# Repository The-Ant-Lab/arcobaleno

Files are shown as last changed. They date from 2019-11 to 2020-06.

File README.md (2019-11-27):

# Arcobaleno<br/>A micropython development board made with The Ant.

This is our first complete project made with The Ant CNC machine.  
It is a development board designed by us and intended to be used with micropython.  

In this repository and in this video [The Ant + Micropython = ARCOBALENO](https://youtu.be/vV_R-Mp-2kI), you will find all the related information.  

If you want to realize the board with The Ant see the hardware folder.  
If you have already built the board and you want to use it see the firmware folder.  

If you liked this project and you want to help us develop new interesting projects, please consider donating using the paypal button here:

paypal (https://www.paypal.com/cgi-bin/webscr?cmd=_s-xclick&hosted_button_id=BTRCVPZUZYW2E)

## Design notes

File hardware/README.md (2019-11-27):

The hardware section is structured as follows:

- design, that contains the schematic and the board layout;
- cam, that contains the CAM outputs of the whole board, comprising gerbers and drill files.
- gcodes, that contains all the gcodes needed to execute the board machining with The Ant (see [here](https://www.youtube.com/channel/UCX44z-SSL7LzcB4xxgUdHHA)).

Before using the gcode files, read carefully the README in the gcodes folder.

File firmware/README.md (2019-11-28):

# Firmware folder structure

The firmware used on this project is based on [micropython](https://github.com/micropython/micropython).  

The firmware folder contains the following directories:  

- ARCOBALENO, that contains the configuration files needed to compile micropython for the Arcobaleno board  
- build-ARCOBALENO, that contains the micropython files already built for the Arcobaleno board  
- micropython, that is the submodule that will contain the micropython repository files.

If you want to use the already built micropython firmware on ARCOBALENO you may load the firmware.dfu or firmware.hex files, using respectively the DFU method with the USB connector or the SWD pins exposed on the ARCOBALENO board.

# Build micropython for ARCOBALENO

If you want to rebuild the micropython for the Arcobaleno board we suggest you to use a linux environment, clone this repository, initialize and update the micropython submodule, copy the whole ARCOBALENO folder in the micropython submodule in the "ports/stm32/boards" directory and then compile the micropython for the ARCOBALENO target board.  

Clone the repository:  
- git clone https://github.com/The-Ant-Lab/arcobaleno.git  

Enter in the firmware folder:  
- cd arcobaleno/firmware  

Initialize and update the micropython submodule:  
- git submodule init  
- git submodule update  

Copy the ARCOBALENO configuration folder in the proper path:
- cp -avr ARCOBALENO/ micropython/ports/stm32/boards/

Enter in the mpy-cross folder and compile it:
- cd micropython/mpy-cross
- make

Enter in the stm32 port folder (in this case from the mpy-cross folder):
- cd ../ports/stm32/

Compile micropython for the Arcobaleno board:
- make BOARD=ARCOBALENO

At the end of the compilation and linking in the "firmware/micropython/ports/stm32" folder there will be a new directory called "build-ARCOBALENO" containing all the built artifacts, and in particular the firmware images that can be uploaded to the Arcobaleno board.

If you want to clean this directory you may run the command:

- make clean BOARD=ARCOBALENO

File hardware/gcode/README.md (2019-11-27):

In this folder you can find the gcode files used to product Arcobaleno with The Ant.

You can see the results of milling operations in this video:

[The Ant + Micropython = ARCOBALENO](https://youtu.be/vV_R-Mp-2kI)

There are some key points to keep in mind before using these gcode files:

	1) The spindle motor used during the milling was a 1500Kv brushless motor
	2) Some grbl parameters were changed before the milling operation
	3) Higher feed rates have been used instead of the suggested ones

[1] The default spindle motor was a 1000Kv one, in theory using a faster motor should allow higher feed rates but with a loss in torque.
We wanted to test it so we changed the spindle motor. The results are pretty good.
   
[2] To allow a faster milling procedures we changed some grbl parameters:

- $110=2000.000 (x max rate, mm/min)
- $111=2000.000 (y max rate, mm/min)
- $112=200.000 (z max rate, mm/min)
- $120=200.000 (x accel, mm/sec^2)
- $121=200.000 (y accel, mm/sec^2)
- $122=10.000 (z accel, mm/sec^2)

Keep in mind that we don't use the max feedrate during milling but only for fast travel movements.

[3] With a faster spindle motor we have tested higher feed rates.
This change only impacts the top.gcode and bottom.gcode files.
If you want to change the feedrate in these files, you can open them in an text editor and change all the occurence of 'F200' with 'F90' (the default value with a spindle motor with 1000Kv).
In this way you can use the gcode files with a slower spindle motor.

Have fun!

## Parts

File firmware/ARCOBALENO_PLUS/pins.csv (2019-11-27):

X1 | PA2
X2 | PA3
X3 | PA0
X4 | PA1
X5 | PA4
X6 | PA5
X7 | PA6
X8 | PA7
X9 | PB6
X10 | PB7
X11 | PC4
X12 | PC5
X13 | Reset
X14 | GND
X15 | 3.3V
X16 | VIN
X17 | PB3
X18 | PC13
X19 | PC0
X20 | PC1
X21 | PC2
X22 | PC3
X23 | A3.3V
X24 | AGND
Y1 | PC6
Y2 | PC7
Y3 | PB10
Y4 | PB9
Y5 | PB12
Y6 | PB13
Y7 | PB14
Y8 | PB15
Y9 | PA8
Y10 | PB8
Y11 | PB0
Y12 | PB1
Y13 | Reset
Y14 | GND
Y15 | 3.3V
Y16 | VIN
SW | PB3
LED_BLUE | PB5
LED_RED | PB1
LED_GREEN | PB0
LED_YELLOW | PB4
SD_D0 | PC8
SD_D1 | PC9
SD_D2 | PC10
SD_D3 | PC11
SD_CMD | PD2
SD_CK | PC12
SD_SW | PA15
USB_VBUS | PA9
USB_DM | PA11
USB_DP | PA12
USB_ID | PA10
OSC32_IN | PC14
OSC32_OUT | PC15

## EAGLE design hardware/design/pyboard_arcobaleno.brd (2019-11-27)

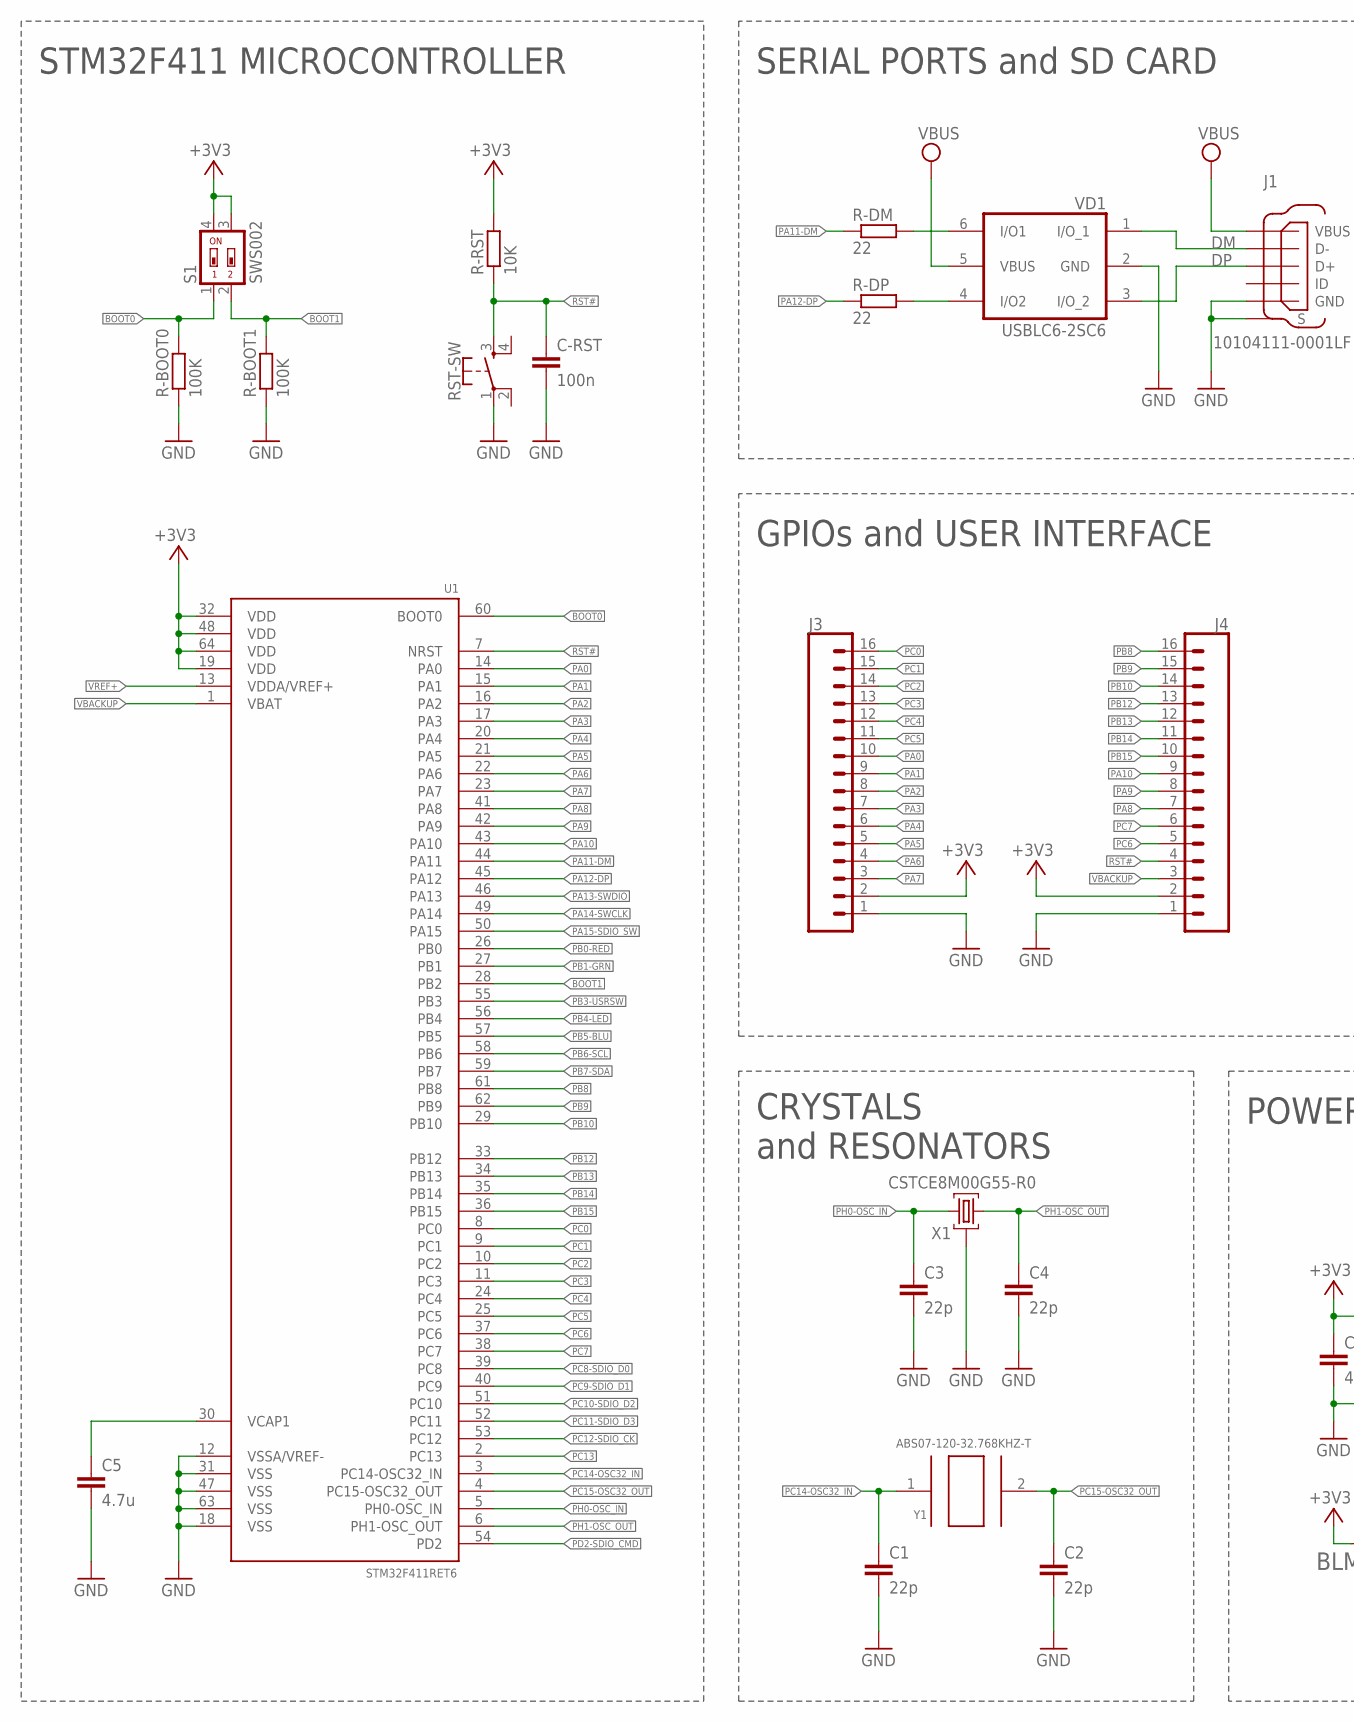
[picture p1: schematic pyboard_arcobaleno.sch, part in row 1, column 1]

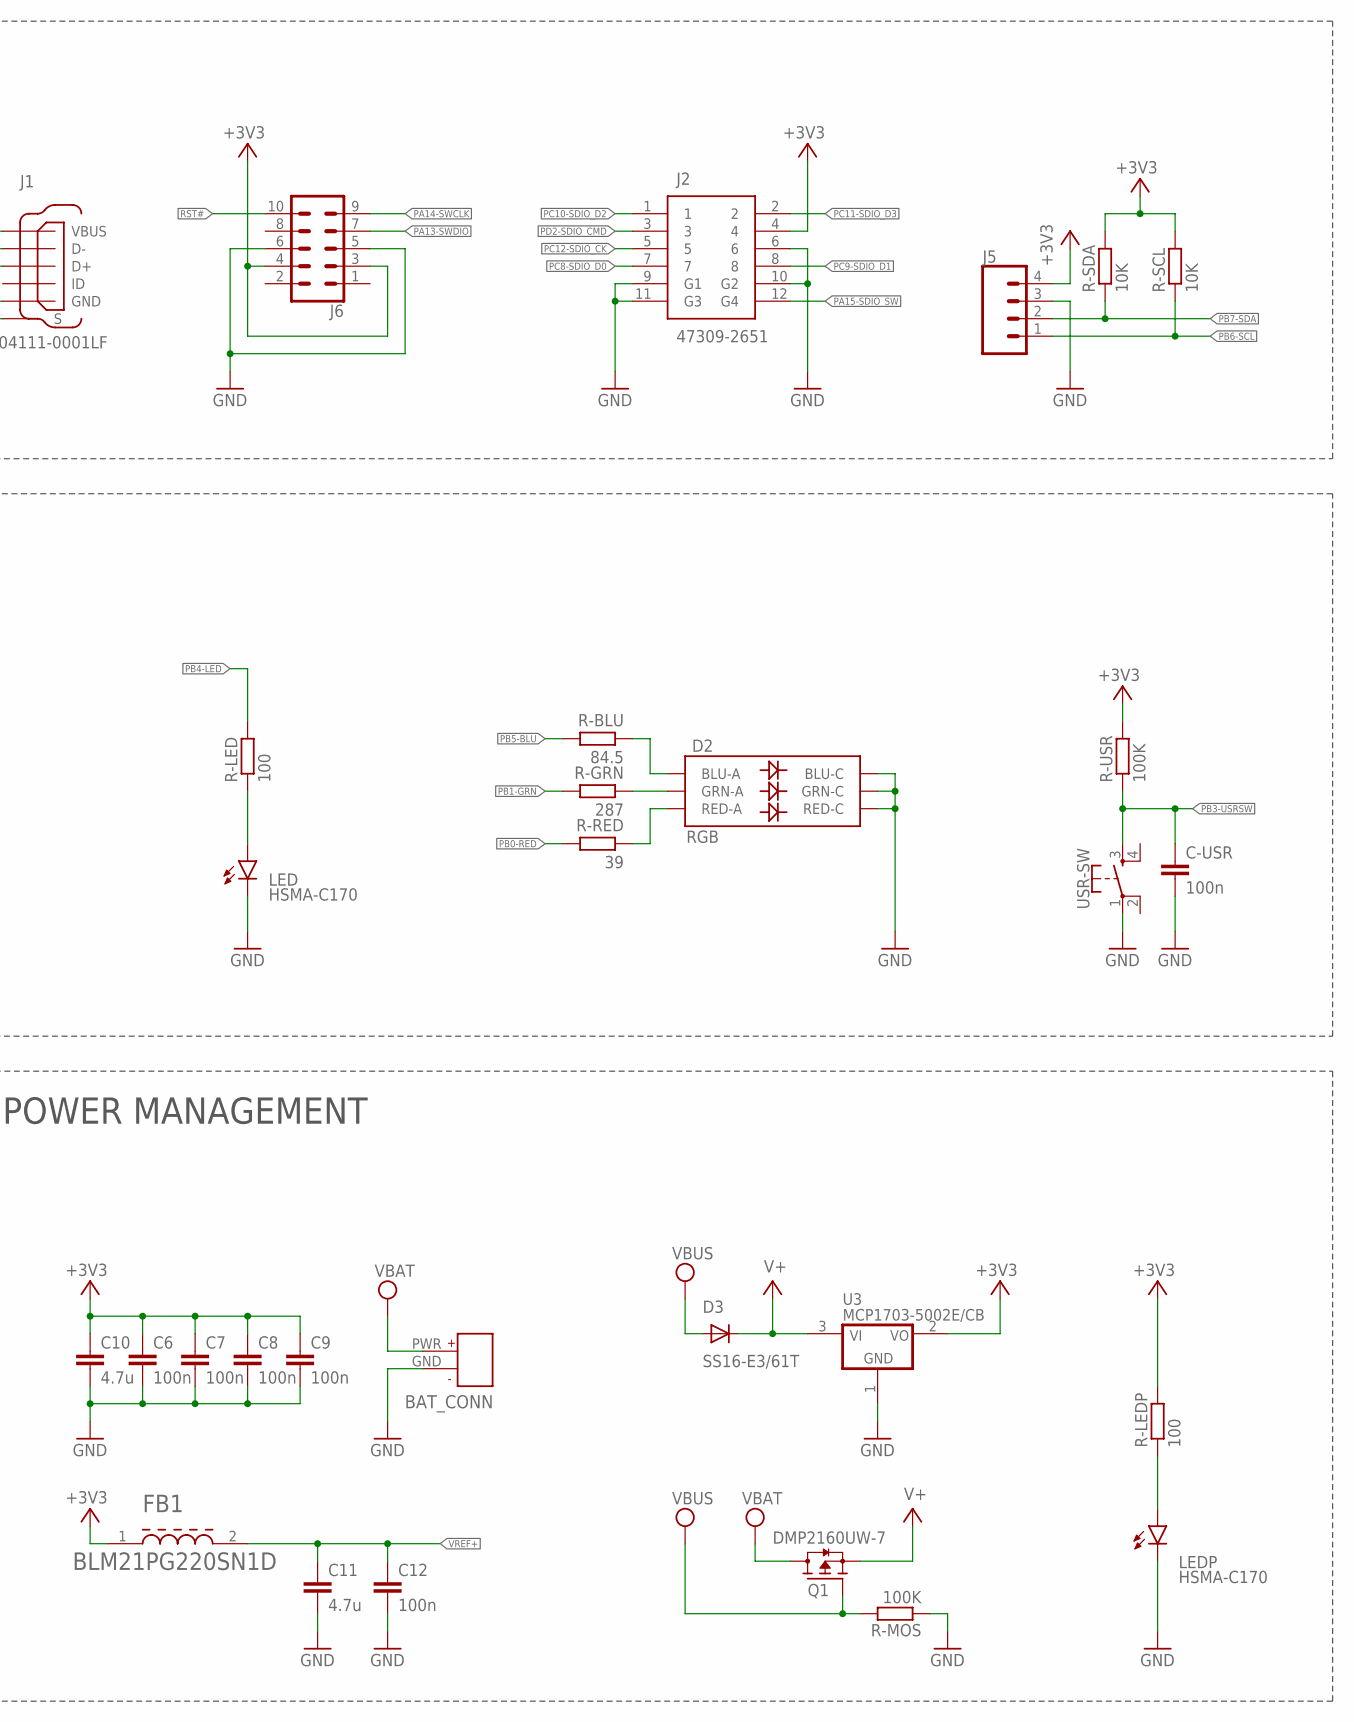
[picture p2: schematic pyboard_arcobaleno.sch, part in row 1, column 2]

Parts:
BAT_CONN: JST_PH_2PIN
C1, C2, C3, C4: 22p; C0603
C5, C10, C11: 4.7u; C1608
C6, C7, C8, C9, C12: 100n; C0603
C-RST: 100n; C0603
C-USR: 100n; C0603
D2: RGB; PLCC-6-LED
D3: SS16-E3/61T; DO214AA
FB1: MURATA_BLM21PG220SN1DMURATA_BLM21PG220SN1D_0_0; MURATA_BLM21PG220SN1D_0
J1: 10104111-0001LF; FRAMATOME_10104111-0001LF
J2: 47309-2651
J3, J4: CONN_16; 1X16
J5: CONN_04; 1X04
J6: CONN_05X2PTH; 2X5
LED: HSMA-C170; CHIPLED_0805
LEDP: HSMA-C170; CHIPLED_0805
Q1: DMP2160UW-7; SOT65P210X110-3N
R-BLU: 84.5; R0603
R-BOOT0, R-BOOT1: 100K; R0603
R-DM: 22; R0603
R-DP: 22; R0603
R-GRN: 287; R0603
R-LED: 100; R0603
R-LEDP: 100; R0603
R-MOS: 100K; R0603
R-RED: 39; R0603
R-RST: 10K; R0603
R-SCL: 10K; R0603
R-SDA: 10K; R0603
R-USR: 100K; R0603
RST-SW: MOMENTARY-SWITCH-SPST-2-SMD-5.2MM; TACTILE_SWITCH_SMD_5.2MM
S1: SWS002; SMS-002
U1: STM32F411RET6; QFP50P1200X1200X160-64N
U3: MCP1703-5002E/CB; SOT23A_MICROCHIP_CB
USR-SW: MOMENTARY-SWITCH-SPST-2-SMD-5.2MM; TACTILE_SWITCH_SMD_5.2MM
VD1: USBLC6-2SC6; SOT-23-6L
X1: CSTCE8M00G55-R0
Y1: ABS07-120-32.768KHZ-T; XTAL_ABS07-120-32.768KHZ-T

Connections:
+3V3: C6.1, C7.1, C8.1, C9.1, C10.1, FB1.1, J2.4, J3.2, J4.2, J5.4, J6.3, J6.4, R-LEDP.2, R-RST.2, R-SCL.2, R-SDA.2, R-USR.2, S1.3, S1.4, U1.19 (VDD), U1.32 (VDD), U1.48 (VDD), U1.64 (VDD), U3.2 (VO)
BOOT0: R-BOOT0.2, S1.1, U1.60 (BOOT0)
BOOT1: R-BOOT1.2, S1.2, U1.28 (PB2)
DM: J1.2 (D-), VD1.1 (I/O_1)
DP: J1.3 (D+), VD1.3 (I/O_2)
GND: BAT_CONN.GND, C1.2, C2.2, C3.2, C4.2, C5.2, C6.2, C7.2, C8.2, C9.2, C10.2, C11.2, C12.2, C-RST.2, C-USR.2, D2.CB (BLU-C), D2.CG (GRN-C), D2.CR (RED-C), J1.5 (GND), J1.6 (S), J1.7 (S), J1.8 (S), J1.9 (S), J2.6, J2.9 (G1), J2.10 (G2), J2.11 (G3), J3.1, J4.1, J5.3, J6.5, J6.6, LED.C, LEDP.C, R-BOOT0.1, R-BOOT1.1, R-MOS.1, RST-SW.1, U1.12 (VSSA/VREF-), U1.18 (VSS), U1.31 (VSS), U1.47 (VSS), U1.63 (VSS), U3.1 (GND), USR-SW.1, VD1.2 (GND), X1.2 (GND)
unnamed: C5.1, U1.30 (VCAP1)
unnamed: R-DM.2, VD1.6 (I/O1)
unnamed: R-DP.2, VD1.4 (I/O2)
unnamed: LED.A, R-LED.1
unnamed: LEDP.A, R-LEDP.1
unnamed: D2.AB (BLU-A), R-BLU.1
unnamed: D2.AG (GRN-A), R-GRN.1
unnamed: D2.AR (RED-A), R-RED.1
PA0: J3.10, U1.14 (PA0)
PA1: J3.9, U1.15 (PA1)
PA2: J3.8, U1.16 (PA2)
PA3: J3.7, U1.17 (PA3)
PA4: J3.6, U1.20 (PA4)
PA5: J3.5, U1.21 (PA5)
PA6: J3.4, U1.22 (PA6)
PA7: J3.3, U1.23 (PA7)
PA8: J4.7, U1.41 (PA8)
PA9: J4.8, U1.42 (PA9)
PA10: J4.9, U1.43 (PA10)
PA11-DM: R-DM.1, U1.44 (PA11)
PA12-DP: R-DP.1, U1.45 (PA12)
PA13-SWDIO: J6.7, U1.46 (PA13)
PA14-SWCLK: J6.9, U1.49 (PA14)
PA15-SDIO_SW: J2.12 (G4), U1.50 (PA15)
PB0-RED: R-RED.2, U1.26 (PB0)
PB1-GRN: R-GRN.2, U1.27 (PB1)
PB3-USRSW: C-USR.1, R-USR.1, U1.55 (PB3), USR-SW.3
PB4-LED: R-LED.2, U1.56 (PB4)
PB5-BLU: R-BLU.2, U1.57 (PB5)
PB6-SCL: J5.1, R-SCL.1, U1.58 (PB6)
PB7-SDA: J5.2, R-SDA.1, U1.59 (PB7)
PB8: J4.16, U1.61 (PB8)
PB9: J4.15, U1.62 (PB9)
PB10: J4.14, U1.29 (PB10)
PB12: J4.13, U1.33 (PB12)
PB13: J4.12, U1.34 (PB13)
PB14: J4.11, U1.35 (PB14)
PB15: J4.10, U1.36 (PB15)
PC0: J3.16, U1.8 (PC0)
PC1: J3.15, U1.9 (PC1)
PC2: J3.14, U1.10 (PC2)
PC3: J3.13, U1.11 (PC3)
PC4: J3.12, U1.24 (PC4)
PC5: J3.11, U1.25 (PC5)
PC6: J4.5, U1.37 (PC6)
PC7: J4.6, U1.38 (PC7)
PC8-SDIO_D0: J2.7, U1.39 (PC8)
PC9-SDIO_D1: J2.8, U1.40 (PC9)
PC10-SDIO_D2: J2.1, U1.51 (PC10)
PC11-SDIO_D3: J2.2, U1.52 (PC11)
PC12-SDIO_CK: J2.5, U1.53 (PC12)
PC13: U1.2 (PC13)
PC14-OSC32_IN: C1.1, U1.3 (PC14-OSC32_IN), Y1.1
PC15-OSC32_OUT: C2.1, U1.4 (PC15-OSC32_OUT), Y1.2
PD2-SDIO_CMD: J2.3, U1.54 (PD2)
PH0-OSC_IN: C3.1, U1.5 (PH0-OSC_IN), X1.1 (INPUT)
PH1-OSC_OUT: C4.1, U1.6 (PH1-OSC_OUT), X1.3 (OUTPUT)
RST#: C-RST.1, J4.4, J6.10, R-RST.1, RST-SW.3, U1.7 (NRST)
V+: D3.C, Q1.2 (S), U3.3 (VI)
VBACKUP: J4.3, U1.1 (VBAT)
VCC: D3.A, J1.1 (VBUS), Q1.1 (G), R-MOS.2, VD1.5 (VBUS)
VEE: BAT_CONN.PWR, Q1.3 (D)
VREF+: C11.1, C12.1, FB1.2, U1.13 (VDDA/VREF+)

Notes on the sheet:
STM32F411 MICROCONTROLLER
SERIAL PORTS and SD CARD
GPIOs and USER INTERFACE
CRYSTALS and RESONATORS
POWER MANAGEMENT

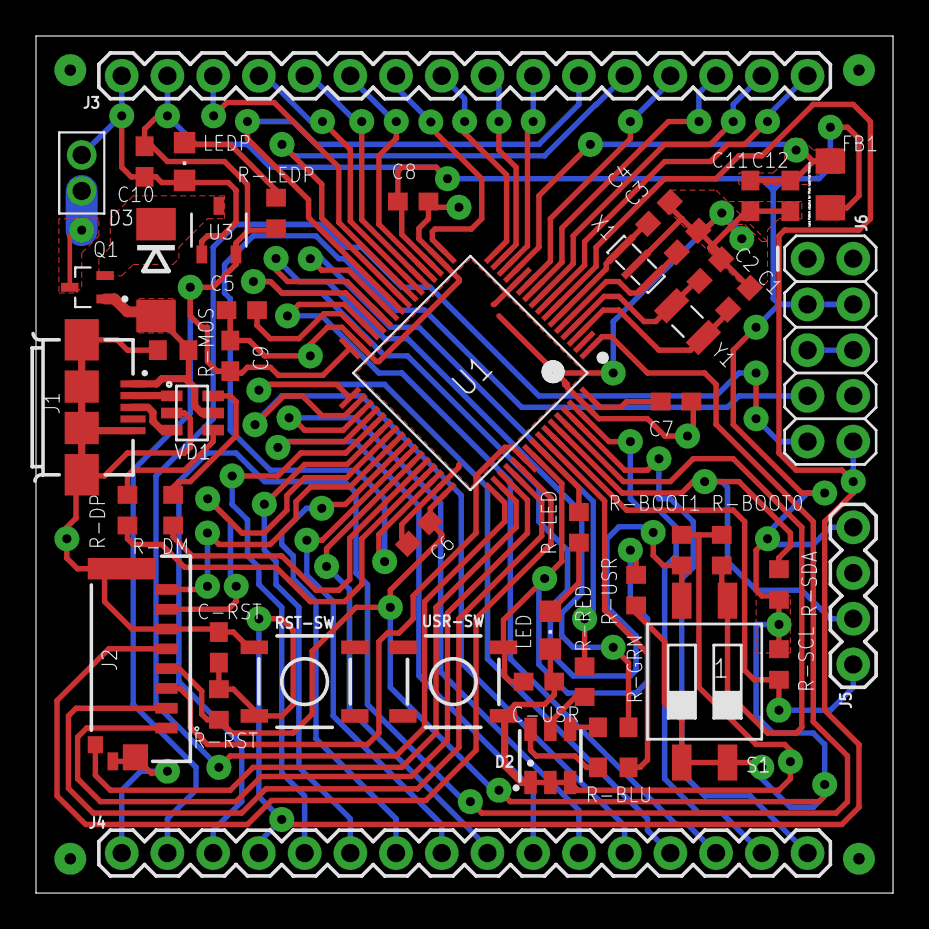
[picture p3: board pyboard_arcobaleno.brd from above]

Board: 2 copper layers, 47.6 x 47.6 mm, 49 parts (0 on the bottom side), 68 nets.

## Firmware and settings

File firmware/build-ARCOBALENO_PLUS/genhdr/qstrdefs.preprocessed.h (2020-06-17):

# 1 "<stdin>"
# 1 "<built-in>"
# 1 "<command-line>"
# 1 "<stdin>"
# 27 "<stdin>"
# 1 "../../py/mpconfig.h" 1
# 62 "../../py/mpconfig.h"
# 1 "./mpconfigport.h" 1
# 31 "./mpconfigport.h"
# 1 "boards/ARCOBALENO_PLUS/mpconfigboard.h" 1
# 32 "./mpconfigport.h" 2
# 1 "./mpconfigboard_common.h" 1
# 30 "./mpconfigboard_common.h"
# 1 "../../lib/stm32lib/STM32F4xx_HAL_Driver/Inc/stm32f4xx_hal.h" 1
# 48 "../../lib/stm32lib/STM32F4xx_HAL_Driver/Inc/stm32f4xx_hal.h"
# 1 "boards/ARCOBALENO_PLUS/stm32f4xx_hal_conf.h" 1







# 1 "./boards/stm32f4xx_hal_conf_base.h" 1
# 30 "./boards/stm32f4xx_hal_conf_base.h"
# 1 "../../lib/stm32lib/STM32F4xx_HAL_Driver/Inc/stm32f4xx_hal_dma.h" 1
# 47 "../../lib/stm32lib/STM32F4xx_HAL_Driver/Inc/stm32f4xx_hal_dma.h"
# 1 "../../lib/stm32lib/STM32F4xx_HAL_Driver/Inc/stm32f4xx_hal_def.h" 1
# 48 "../../lib/stm32lib/STM32F4xx_HAL_Driver/Inc/stm32f4xx_hal_def.h"
# 1 "../../lib/stm32lib/CMSIS/STM32F4xx/Include/stm32f4xx.h" 1
# 189 "../../lib/stm32lib/CMSIS/STM32F4xx/Include/stm32f4xx.h"
# 1 "../../lib/stm32lib/CMSIS/STM32F4xx/Include/stm32f413xx.h" 1
# 84 "../../lib/stm32lib/CMSIS/STM32F4xx/Include/stm32f413xx.h"
typedef enum
{

  NonMaskableInt_IRQn = -14,
  MemoryManagement_IRQn = -12,
  BusFault_IRQn = -11,
  UsageFault_IRQn = -10,
  SVCall_IRQn = -5,
  DebugMonitor_IRQn = -4,
  PendSV_IRQn = -2,
  SysTick_IRQn = -1,

  WWDG_IRQn = 0,
  PVD_IRQn = 1,
  TAMP_STAMP_IRQn = 2,
  RTC_WKUP_IRQn = 3,
  FLASH_IRQn = 4,
  RCC_IRQn = 5,
  EXTI0_IRQn = 6,
  EXTI1_IRQn = 7,
  EXTI2_IRQn = 8,
  EXTI3_IRQn = 9,
  EXTI4_IRQn = 10,
  DMA1_Stream0_IRQn = 11,
  DMA1_Stream1_IRQn = 12,
  DMA1_Stream2_IRQn = 13,
  DMA1_Stream3_IRQn = 14,
  DMA1_Stream4_IRQn = 15,
  DMA1_Stream5_IRQn = 16,
  DMA1_Stream6_IRQn = 17,
  ADC_IRQn = 18,
  CAN1_TX_IRQn = 19,
  CAN1_RX0_IRQn = 20,
  CAN1_RX1_IRQn = 21,
  CAN1_SCE_IRQn = 22,
  EXTI9_5_IRQn = 23,
  TIM1_BRK_TIM9_IRQn = 24,
  TIM1_UP_TIM10_IRQn = 25,
  TIM1_TRG_COM_TIM11_IRQn = 26,
  TIM1_CC_IRQn = 27,
  TIM2_IRQn = 28,
  TIM3_IRQn = 29,
  TIM4_IRQn = 30,
  I2C1_EV_IRQn = 31,
  I2C1_ER_IRQn = 32,
  I2C2_EV_IRQn = 33,
  I2C2_ER_IRQn = 34,
  SPI1_IRQn = 35,
  SPI2_IRQn = 36,
  USART1_IRQn = 37,
  USART2_IRQn = 38,
  USART3_IRQn = 39,
  EXTI15_10_IRQn = 40,
  RTC_Alarm_IRQn = 41,
  OTG_FS_WKUP_IRQn = 42,
  TIM8_BRK_TIM12_IRQn = 43,
  TIM8_UP_TIM13_IRQn = 44,
  TIM8_TRG_COM_TIM14_IRQn = 45,
  TIM8_CC_IRQn = 46,
  DMA1_Stream7_IRQn = 47,
  SDIO_IRQn = 49,
  TIM5_IRQn = 50,
  SPI3_IRQn = 51,
  UART4_IRQn = 52,
  UART5_IRQn = 53,
  TIM6_DAC_IRQn = 54,
  TIM7_IRQn = 55,
  DMA2_Stream0_IRQn = 56,
  DMA2_Stream1_IRQn = 57,
  DMA2_Stream2_IRQn = 58,
  DMA2_Stream3_IRQn = 59,
  DMA2_Stream4_IRQn = 60,
  DFSDM1_FLT0_IRQn = 61,
  DFSDM1_FLT1_IRQn = 62,
  CAN2_TX_IRQn = 63,
  CAN2_RX0_IRQn = 64,
  CAN2_RX1_IRQn = 65,
  CAN2_SCE_IRQn = 66,
  OTG_FS_IRQn = 67,
  DMA2_Stream5_IRQn = 68,
  DMA2_Stream6_IRQn = 69,
  DMA2_Stream7_IRQn = 70,
  USART6_IRQn = 71,
  I2C3_EV_IRQn = 72,
  I2C3_ER_IRQn = 73,
  CAN3_TX_IRQn = 74,
  CAN3_RX0_IRQn = 75,
  CAN3_RX1_IRQn = 76,
  CAN3_SCE_IRQn = 77,
  RNG_IRQn = 80,
  FPU_IRQn = 81,
  UART7_IRQn = 82,
  UART8_IRQn = 83,
  SPI4_IRQn = 84,
  SPI5_IRQn = 85,
  SAI1_IRQn = 87,
  UART9_IRQn = 88,
  UART10_IRQn = 89,
  QUADSPI_IRQn = 92,
  FMPI2C1_EV_IRQn = 95,
  FMPI2C1_ER_IRQn = 96,
  LPTIM1_IRQn = 97,
  DFSDM2_FLT0_IRQn = 98,
  DFSDM2_FLT1_IRQn = 99,
  DFSDM2_FLT2_IRQn = 100,
  DFSDM2_FLT3_IRQn = 101
} IRQn_Type;





# 1 "../../lib/cmsis/inc/core_cm4.h" 1
# 34 "../../lib/cmsis/inc/core_cm4.h"
# 1 "/usr/lib/gcc/arm-none-eabi/6.3.1/include/stdint.h" 1 3 4
# 9 "/usr/lib/gcc/arm-none-eabi/6.3.1/include/stdint.h" 3 4
# 1 "/usr/include/newlib/stdint.h" 1 3 4
# 12 "/usr/include/newlib/stdint.h" 3 4
# 1 "/usr/include/newlib/machine/_default_types.h" 1 3 4







# 1 "/usr/include/newlib/sys/features.h" 1 3 4
# 28 "/usr/include/newlib/sys/features.h" 3 4
# 1 "/usr/include/newlib/_newlib_version.h" 1 3 4
# 29 "/usr/include/newlib/sys/features.h" 2 3 4
# 9 "/usr/include/newlib/machine/_default_types.h" 2 3 4
# 27 "/usr/include/newlib/machine/_default_types.h" 3 4

# 27 "/usr/include/newlib/machine/_default_types.h" 3 4
typedef signed char __int8_t;

typedef unsigned char __uint8_t;
# 41 "/usr/include/newlib/machine/_default_types.h" 3 4
typedef short int __int16_t;

typedef short unsigned int __uint16_t;
# 63 "/usr/include/newlib/machine/_default_types.h" 3 4
typedef long int __int32_t;

typedef long unsigned int __uint32_t;
# 89 "/usr/include/newlib/machine/_default_types.h" 3 4
typedef long long int __int64_t;

typedef long long unsigned int __uint64_t;
# 120 "/usr/include/newlib/machine/_default_types.h" 3 4
typedef signed char __int_least8_t;

typedef unsigned char __uint_least8_t;
# 146 "/usr/include/newlib/machine/_default_types.h" 3 4
typedef short int __int_least16_t;

typedef short unsigned int __uint_least16_t;
# 168 "/usr/include/newlib/machine/_default_types.h" 3 4
typedef long int __int_least32_t;
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

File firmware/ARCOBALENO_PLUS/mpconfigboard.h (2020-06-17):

#define MICROPY_HW_BOARD_NAME       "ARCOBALENO_PLUS"
#define MICROPY_HW_MCU_NAME         "STM32F413"

#define MICROPY_HW_HAS_SWITCH       (1)
#define MICROPY_HW_HAS_FLASH        (1)
#define MICROPY_HW_HAS_LCD          (1)
#define MICROPY_HW_ENABLE_RTC       (1)
#define MICROPY_HW_ENABLE_USB       (1)
#define MICROPY_HW_ENABLE_SERVO     (1)
#define MICROPY_HW_ENABLE_SDCARD    (1)

// HSE is 12MHz
#define MICROPY_HW_CLK_PLLM (12)
#define MICROPY_HW_CLK_PLLN (192)
#define MICROPY_HW_CLK_PLLP (RCC_PLLP_DIV2)
#define MICROPY_HW_CLK_PLLQ (4)
#define MICROPY_HW_CLK_LAST_FREQ (1)

// For 2.7 to 3.6 V, 75 to 100 MHz: 3 wait states.
#define MICROPY_HW_FLASH_LATENCY    FLASH_LATENCY_3

// Pyboard lite has an optional 32kHz crystal
#define MICROPY_HW_RTC_USE_LSE      (1)
#define MICROPY_HW_RTC_USE_US       (0)
#define MICROPY_HW_RTC_USE_CALOUT   (1)

// UART config
#define MICROPY_HW_UART1_NAME   "XB"
#define MICROPY_HW_UART1_TX     (pin_B6)
#define MICROPY_HW_UART1_RX     (pin_B7)
#define MICROPY_HW_UART2_NAME   "XA"
#define MICROPY_HW_UART2_TX     (pin_A2)
#define MICROPY_HW_UART2_RX     (pin_A3)
#define MICROPY_HW_UART2_RTS    (pin_A1)
#define MICROPY_HW_UART2_CTS    (pin_A0)
#define MICROPY_HW_UART6_NAME   "YA"
#define MICROPY_HW_UART6_TX     (pin_C6)
#define MICROPY_HW_UART6_RX     (pin_C7)

// I2C busses
#define MICROPY_HW_I2C1_NAME "X"
#define MICROPY_HW_I2C1_SCL (pin_B6)
#define MICROPY_HW_I2C1_SDA (pin_B7)
#define MICROPY_HW_I2C3_NAME "Y"
#define MICROPY_HW_I2C3_SCL (pin_A8)
#define MICROPY_HW_I2C3_SDA (pin_B8)

// SPI busses
#define MICROPY_HW_SPI1_NAME "X"
#define MICROPY_HW_SPI1_NSS  (pin_A4) // X5
#define MICROPY_HW_SPI1_SCK  (pin_A5) // X6
#define MICROPY_HW_SPI1_MISO (pin_A6) // X7
#define MICROPY_HW_SPI1_MOSI (pin_A7) // X8
#define MICROPY_HW_SPI2_NAME "Y"
#define MICROPY_HW_SPI2_NSS  (pin_B12) // Y5
#define MICROPY_HW_SPI2_SCK  (pin_B13) // Y6
#define MICROPY_HW_SPI2_MISO (pin_B14) // Y7
#define MICROPY_HW_SPI2_MOSI (pin_B15) // Y8

// USRSW has no pullup or pulldown, and pressing the switch makes the input go low
#define MICROPY_HW_USRSW_PIN        (pin_B3)
#define MICROPY_HW_USRSW_PULL       (GPIO_PULLUP)
#define MICROPY_HW_USRSW_EXTI_MODE  (GPIO_MODE_IT_FALLING)
#define MICROPY_HW_USRSW_PRESSED    (0)

// The pyboard has 4 LEDs
#define MICROPY_HW_LED1             (pin_B1) // red
#define MICROPY_HW_LED2             (pin_B0) // green
#define MICROPY_HW_LED3             (pin_B4) // yellow
#define MICROPY_HW_LED4             (pin_B5)  // blue
#define MICROPY_HW_LED1_PWM         { TIM3, 3, TIM_CHANNEL_4, GPIO_AF2_TIM3 }
#define MICROPY_HW_LED2_PWM         { TIM3, 3, TIM_CHANNEL_3, GPIO_AF2_TIM3 }
#define MICROPY_HW_LED3_PWM         { TIM3, 3, TIM_CHANNEL_1, GPIO_AF2_TIM3 }
#define MICROPY_HW_LED4_PWM         { TIM3, 3, TIM_CHANNEL_2, GPIO_AF2_TIM3 }
#define MICROPY_HW_LED_ON(pin)      (mp_hal_pin_high(pin))
#define MICROPY_HW_LED_OFF(pin)     (mp_hal_pin_low(pin))

// SD card detect switch
#define MICROPY_HW_SDCARD_DETECT_PIN        (pin_A15)
#define MICROPY_HW_SDCARD_DETECT_PULL       (GPIO_PULLUP)
#define MICROPY_HW_SDCARD_DETECT_PRESENT    (GPIO_PIN_RESET)

// USB config
#define MICROPY_HW_USB_FS              (1)

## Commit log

2019-11-27 Adding arcobaleno config folder, arcobaleno built micropython files, micropython submodule
    [pins.csv]
2019-11-27 Added Arcobaleno board design and CAM output files
    [pyboard_arcobaleno.brd, pyboard_arcobaleno.sch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]
2019-11-28 Correction of wrong Alternate Function numbers.
    [mpconfigboard.h]
2020-02-18 Updated micropython submodule to latest version, since they corrected the bug on sd card mount.
    [frozen_content.c, qstrdefs.preprocessed.h]
2020-06-17 Adding Arcobaleno Plus configurationa and built artifacts
    [pins.csv]

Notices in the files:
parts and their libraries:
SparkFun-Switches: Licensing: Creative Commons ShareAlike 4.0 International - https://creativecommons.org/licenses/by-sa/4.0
